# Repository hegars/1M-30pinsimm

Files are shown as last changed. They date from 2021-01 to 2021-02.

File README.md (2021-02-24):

# 1M-30pinsimm

KiCAD design for a 1MByte 30 pin SIMM Fast Page Mode Dynamic Random Access Memory Module Design

WORK IN PROGRESS - Dont let your blue smoke out.

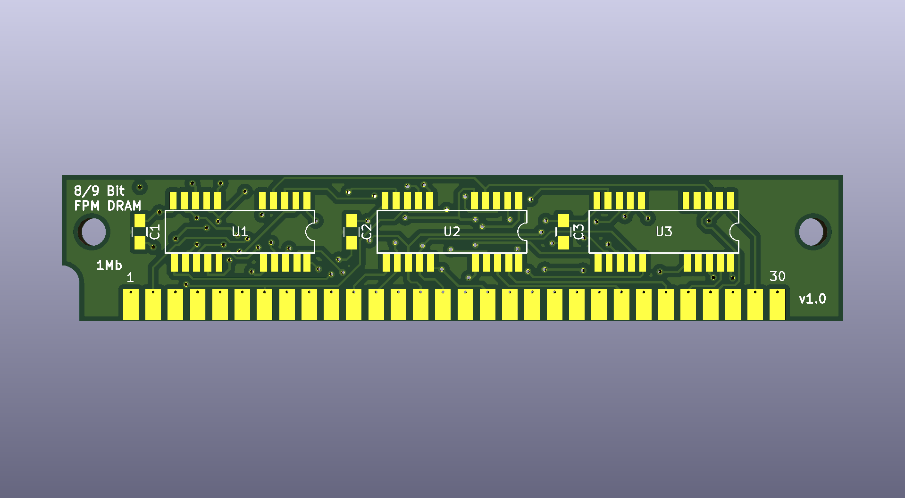
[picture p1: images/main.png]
1msim30


## Real Boards

Boards back from JLCPCB
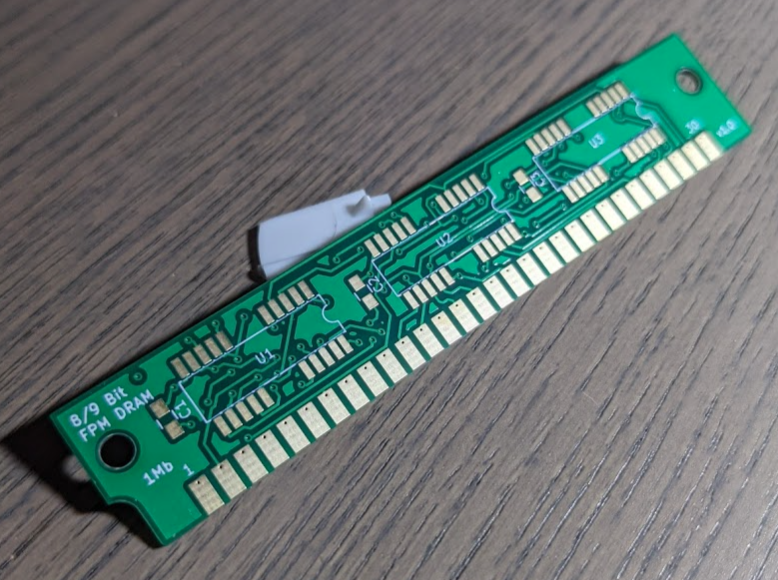
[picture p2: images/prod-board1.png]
prod1


Seated in test socket fine, aliginmet is great
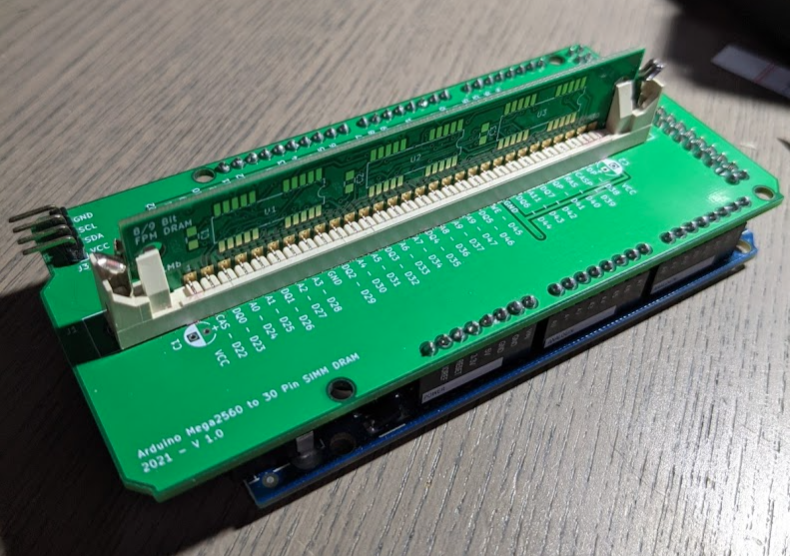
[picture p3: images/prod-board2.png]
prod2


## Test Chips

Donor 72pin dual sided ram, 99cent ebay find which has enough chips for 8 boards. 

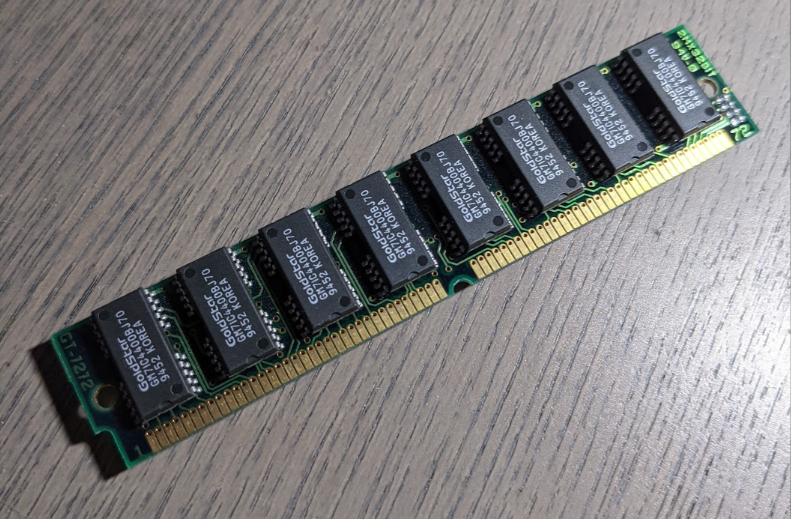
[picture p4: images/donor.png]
donor


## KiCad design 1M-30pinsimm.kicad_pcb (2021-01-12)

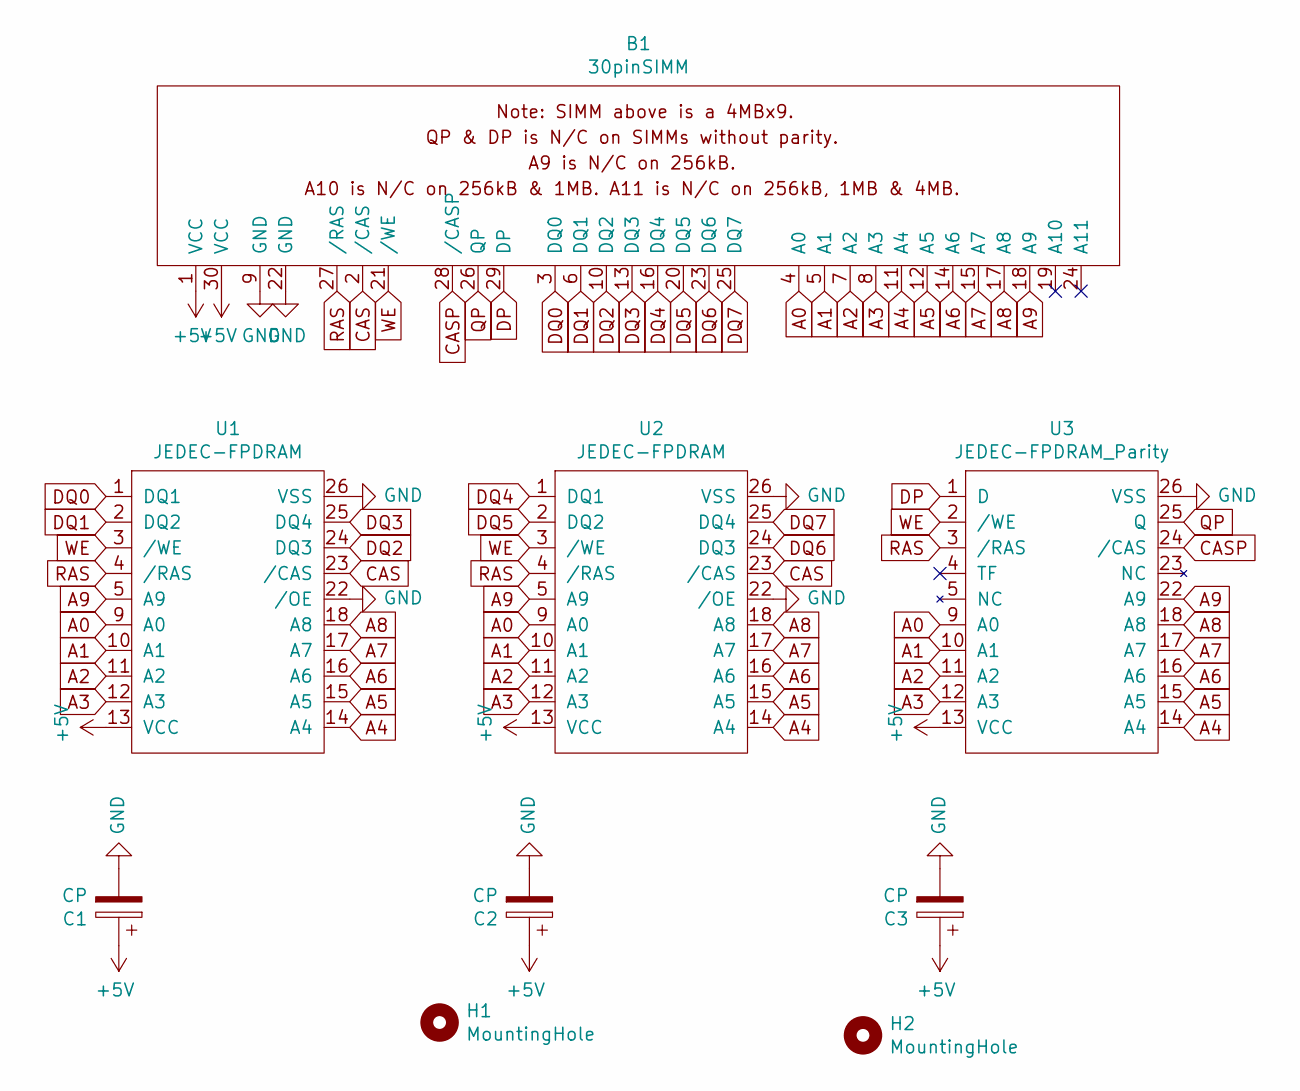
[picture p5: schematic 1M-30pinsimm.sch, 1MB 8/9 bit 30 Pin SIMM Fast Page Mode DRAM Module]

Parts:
B1: 30pinSIMM
C1, C2, C3: CP; C_0805_HandSoldering
H1, H2: MountingHole; MountingHole_3.2mm_M3
U1, U2: JEDEC-FPDRAM; SOJ-20
U3: JEDEC-FPDRAM_Parity; SOJ-20

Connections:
+5V: B1.1 (VCC), B1.30 (VCC), C1.1, C2.1, C3.1, U1.13 (VCC), U2.13 (VCC), U3.13 (VCC)
A0: B1.4 (A0), U1.9 (A0), U2.9 (A0), U3.9 (A0)
A1: B1.5 (A1), U1.10 (A1), U2.10 (A1), U3.10 (A1)
A2: B1.7 (A2), U1.11 (A2), U2.11 (A2), U3.11 (A2)
A3: B1.8 (A3), U1.12 (A3), U2.12 (A3), U3.12 (A3)
A4: B1.11 (A4), U1.14 (A4), U2.14 (A4), U3.14 (A4)
A5: B1.12 (A5), U1.15 (A5), U2.15 (A5), U3.15 (A5)
A6: B1.14 (A6), U1.16 (A6), U2.16 (A6), U3.16 (A6)
A7: B1.15 (A7), U1.17 (A7), U2.17 (A7), U3.17 (A7)
A8: B1.17 (A8), U1.18 (A8), U2.18 (A8), U3.18 (A8)
A9: B1.18 (A9), U1.5 (A9), U2.5 (A9), U3.22 (A9)
CAS: B1.2 (/CAS), U1.23 (/CAS), U2.23 (/CAS)
CASP: B1.28 (/CASP), U3.24 (/CAS)
DP: B1.29 (DP), U3.1 (D)
DQ0: B1.3 (DQ0), U1.1 (DQ1)
DQ1: B1.6 (DQ1), U1.2 (DQ2)
DQ2: B1.10 (DQ2), U1.24 (DQ3)
DQ3: B1.13 (DQ3), U1.25 (DQ4)
DQ4: B1.16 (DQ4), U2.1 (DQ1)
DQ5: B1.20 (DQ5), U2.2 (DQ2)
DQ6: B1.23 (DQ6), U2.24 (DQ3)
DQ7: B1.25 (DQ7), U2.25 (DQ4)
GND: B1.9 (GND), B1.22 (GND), C1.2, C2.2, C3.2, U1.22 (/OE), U1.26 (VSS), U2.22 (/OE), U2.26 (VSS), U3.26 (VSS)
QP: B1.26 (QP), U3.25 (Q)
RAS: B1.27 (/RAS), U1.4 (/RAS), U2.4 (/RAS), U3.3 (/RAS)
WE: B1.21 (/WE), U1.3 (/WE), U2.3 (/WE), U3.2 (/WE)

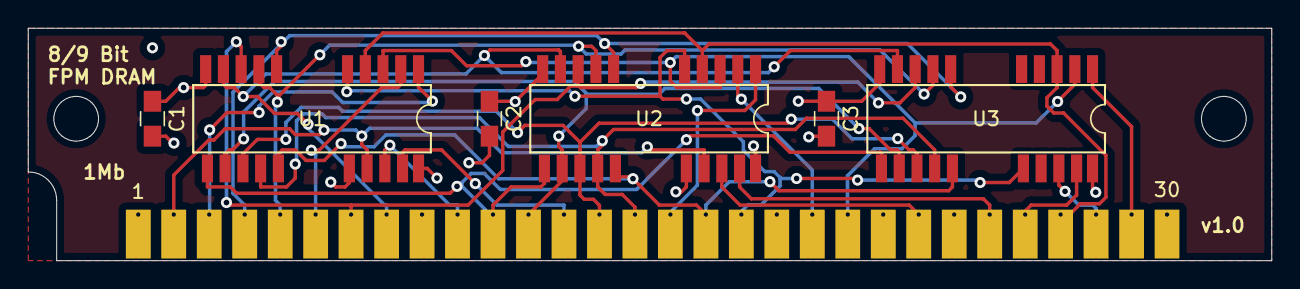
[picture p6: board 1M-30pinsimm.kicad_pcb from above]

Board: 4 copper layers, 89.0 x 16.6 mm, 9 parts (0 on the bottom side), 26 nets.

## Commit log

2021-01-12 generate gerbers
    [1M-30pinsimm-B_Cu.gbr, 1M-30pinsimm-B_Mask.gbr, 1M-30pinsimm-B_Paste.gbr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]
2021-01-12 cleaned up tracks
    [1M-30pinsimm.kicad_pcb]
2021-01-12 regenerate gerbers
    [1M-30pinsimm-B_Cu.gbr, 1M-30pinsimm-B_Mask.gbr, 1M-30pinsimm-B_Paste.gbr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]
2021-01-12 update title frame
    [1M-30pinsimm.sch]
2021-01-12 change caps
    [1M-30pinsimm.sch]
2021-01-12 update gerbers
    [1M-30pinsimm-B_Cu.gbr, 1M-30pinsimm-B_Mask.gbr, 1M-30pinsimm-B_Paste.gbr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]
2021-02-24 real boards
